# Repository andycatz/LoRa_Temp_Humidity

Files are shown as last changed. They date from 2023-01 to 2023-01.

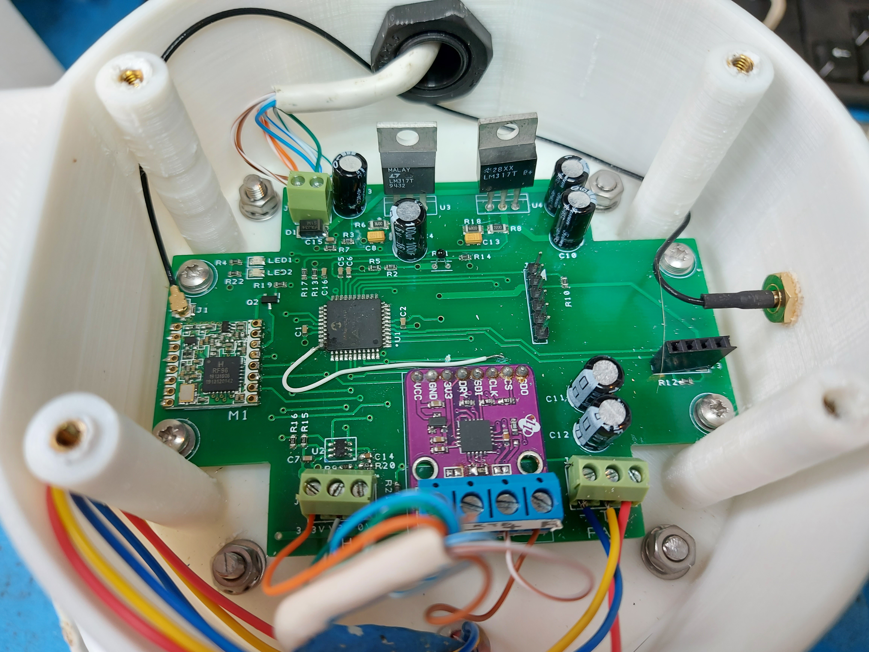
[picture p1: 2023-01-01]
Photos/20210724_112519.jpg

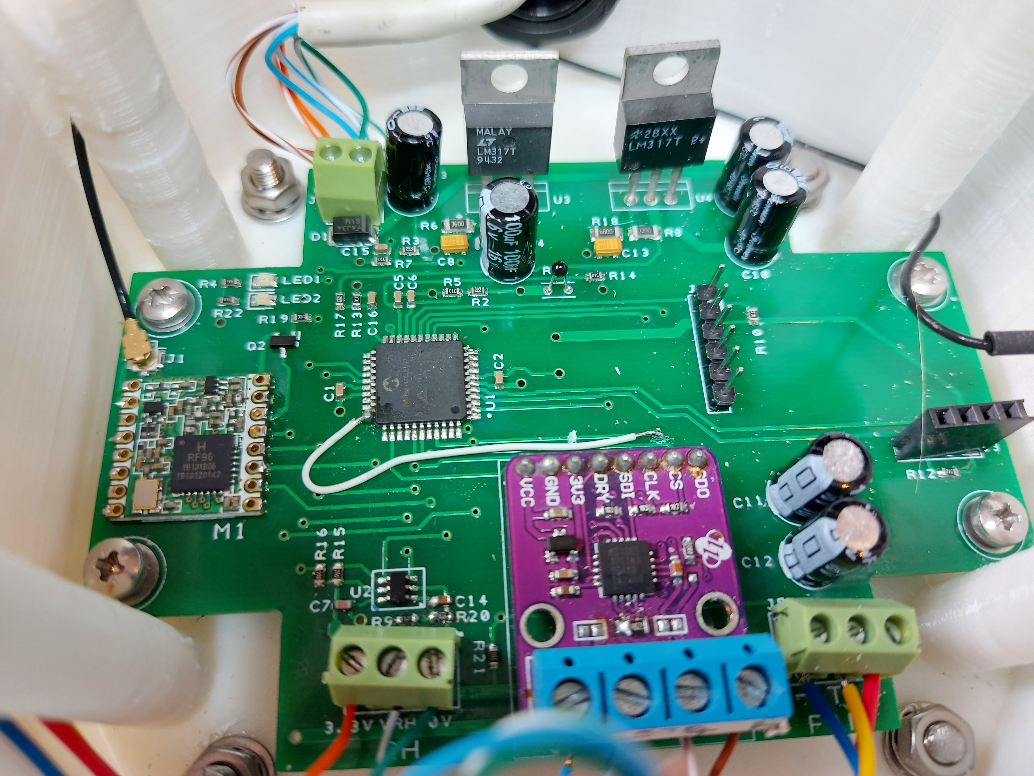
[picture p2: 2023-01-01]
Photos/20210724_112526.jpg

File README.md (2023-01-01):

# LoRa_Temp_Humidity
Outdoor temperature and humidity sensor with LoRa transmitter
The microcontroller wakes up once per minute and takes a temperature and relative humidity reading.
It then transmits that data as a 50 byte packet using the LoRa transmitter module (RFM95W).
The data is received by the LoRa receiver on the Raspberry pi.
All calibration is done at the receiver end.
This does NOT use LoRaWAN.
Schematic and PCB are designed using Design Spark.
Enclosure was designed using Fusion 360.
Software was written in C using MPLab X with XC8 compiler.

This sensor requires DC 9V power to run the electronics and the fan.  A battery is possible but
it would need to be reasonable large e.g. lead-acid 12V.
The fan is used to pass ambient air over the sensors and to prevent the outer walls of the enclosure
from heating up the sensor.
The 12V fan is run at approximately 5V so that it should have a long life time.  An IP65 or thereabouts
rated fan should be used, otherwise the fan bearings will rust within a few months.
In addition to the outside temperature and relative humidity, the sensor also reports back its own
internal temperature as well as the supply voltage, microcontroller supply voltage and fan voltage.

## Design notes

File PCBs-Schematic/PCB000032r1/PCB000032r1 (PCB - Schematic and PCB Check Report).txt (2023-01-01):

Schematic and PCB Check Report
------------------------------

Report Written:     Saturday, September 07, 2019
Project Path:       D:\Documents\Design Spark\000000's\PCB000032r1\PCB000032r1.prj
Design Path:        D:\Documents\Design Spark\000000's\PCB000032r1\PCB000032r1.pcb
Design Title:       
Created:            07/09/2019 17:56:36
Last Saved:         07/09/2019 18:29:10
Editing Time:       32 min
Units:              mm (precision 2)

Checking integrity of Schematic and Pcb designs in project "PCB000032r1"
========================================================================

End Of Report.

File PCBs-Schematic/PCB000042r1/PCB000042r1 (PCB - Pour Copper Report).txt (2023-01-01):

Pour Copper Report
------------------

Report Written:     Friday, June 25, 2021
Project Path:       D:\Documents\Design Spark\000000's\PCB000042r1\PCB000042r1.prj
Design Path:        D:\Documents\Design Spark\000000's\PCB000042r1\PCB000042r1.pcb
Design Title:       
Created:            25/05/2021 19:34:24
Last Saved:         25/06/2021 18:57:42
Editing Time:       444 min
Units:              mm (precision 2)

End Of Report.

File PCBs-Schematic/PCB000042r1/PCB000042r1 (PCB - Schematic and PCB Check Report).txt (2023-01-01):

Schematic and PCB Check Report
------------------------------

Report Written:     Thursday, June 24, 2021
Project Path:       D:\Documents\Design Spark\000000's\PCB000042r1\PCB000042r1.prj
Design Path:        D:\Documents\Design Spark\000000's\PCB000042r1\PCB000042r1.pcb
Design Title:       
Created:            25/05/2021 19:34:24
Last Saved:         24/06/2021 20:44:52
Editing Time:       335 min
Units:              mm (precision 2)

Checking integrity of Schematic and Pcb designs in project "PCB000042r1"
========================================================================

End Of Report.

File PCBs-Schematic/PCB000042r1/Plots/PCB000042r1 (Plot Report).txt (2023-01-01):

Plot Report
-----------

Report Written:     Friday, June 25, 2021
Project Path:       D:\Documents\Design Spark\000000's\PCB000042r1\PCB000042r1.prj
Design Path:        D:\Documents\Design Spark\000000's\PCB000042r1\PCB000042r1.pcb
Design Title:       
Created:            25/05/2021 19:34:24
Last Saved:         25/06/2021 20:06:50
Editing Time:       514 min
Units:              mm (precision 2)

Device Settings
===============

Gerber Settings
===============

    Leading zero suppression.
    G01 assumed throughout.
    Line termination <*> <CR> <LF>.
    3.5 format absolute inches.

    Format commands defined in Gerber file.
    Aperture table defined in Gerber file.
    Hardware arcs allowed.

Drill Settings
==============

    Excellon Format 2
    Format 3.5 absolute in mm.
    Zero suppression Leading

Plots Output
============

Gerber Output
=============

D:\Documents\Design Spark\000000's\PCB000042r1\Plots\PCB000042r1 - Top Silkscreen.gbr

    Layers:
    ------------------
    Top Silkscreen

    D-Code Shape  (thou)
    -----------------------
    D10    Round 5.00
    D11    Round 7.87
    D12    Round 8.00
    D13    Round 3.94
    D14    Round 10.00
    D17    Round 25.00

Gerber Output
=============

D:\Documents\Design Spark\000000's\PCB000042r1\Plots\PCB000042r1 - Top Copper.gbr

    Layers:
    --------------
    Top Copper

    D-Code Shape  (thou)
    --------------------------------------------------------------
    D16    Round 50.00
    D17    Round 25.00
    D19    Round 15.00
    D70    Round 48.00
    D71    Rectangle 22.00 X 59.00  Rotation 90
    D20    Rectangle 22.00 X 59.00
    D22    Square 80.00
    D23    Round 80.00
    D24    Rectangle 35.43 X 55.12
    D26    Rectangle 33.46 X 39.37
    D27    Rectangle 33.46 X 39.37  Rotation 90
    D28    Rectangle 30.71 X 38.58  Rotation 90
    D29    Rectangle 23.62 X 41.34
    D72    Rectangle 30.71 X 38.58
    D73    Round 43.31
    D75    Rectangle 41.34 X 86.61
    D76    Rectangle 39.37 X 41.34
    D77    Round 251.97
    D103   Rounded Rectangle 59.06 X 98.43 X 19.69  Rotation 90
    D104   Round 60.00
    D123   Round 56.00
    D124   Rectangle 21.65 X 47.24  Rotation 90
    D125   Square 59.06
    D126   Round 70.00
    D127   Rectangle 68.90 X 104.33
    D128   Square 60.00
    D129   Rectangle 41.34 X 70.87
    D130   Rectangle 43.31 X 70.87
    D131   Rectangle 24.41 X 57.87
    D132   Rectangle 59.00 X 59.00  Rotation 90
    D133   Round 59.00

Gerber Output
=============

D:\Documents\Design Spark\000000's\PCB000042r1\Plots\PCB000042r1 - Top Solder Mask.gbr

    Layers:
    -------------------
    Top Solder Mask

    D-Code Shape  (thou)
    --------------------------------------------------------------
    D81    Rectangle 28.00 X 65.00  Rotation 90
    D82    Rectangle 28.00 X 65.00
    D84    Square 86.00
    D85    Round 86.00
    D86    Rectangle 41.43 X 61.12
    D88    Rectangle 39.46 X 45.37
    D89    Rectangle 39.46 X 45.37  Rotation 90
    D90    Rectangle 36.71 X 44.58  Rotation 90
    D91    Rectangle 29.62 X 47.34
    D92    Rectangle 36.71 X 44.58
    D93    Round 49.31
    D95    Rectangle 47.34 X 92.61
    D96    Rectangle 45.37 X 47.34
    D97    Round 257.97
    D121   Rounded Rectangle 59.06 X 98.43 X 19.69  Rotation 90
    D134   Rectangle 27.65 X 53.24  Rotation 90
    D135   Square 65.06
    D136   Round 66.00
    D137   Round 76.00
    D138   Rectangle 74.90 X 110.33
    D139   Square 66.00
    D140   Rectangle 47.34 X 76.87
    D141   Rectangle 49.31 X 76.87
    D142   Rectangle 30.41 X 63.87
    D143   Rectangle 65.00 X 65.00  Rotation 90
    D144   Round 65.00

Gerber Output
=============

D:\Documents\Design Spark\000000's\PCB000042r1\Plots\PCB000042r1 - Bottom Copper.gbr

    Layers:
    -----------------
    Bottom Copper

    D-Code Shape  (thou)
    --------------------------------------------------------------
    D10    Round 5.00
    D14    Round 10.00
    D16    Round 50.00
    D19    Round 15.00
    D70    Round 48.00
    D22    Square 80.00
    D23    Round 80.00
    D73    Round 43.31
    D77    Round 251.97
    D103   Rounded Rectangle 59.06 X 98.43 X 19.69  Rotation 90
    D104   Round 60.00
    D123   Round 56.00
    D125   Square 59.06
    D126   Round 70.00
    D128   Square 60.00
    D132   Rectangle 59.00 X 59.00  Rotation 90
    D133   Round 59.00

Gerber Output
=============

D:\Documents\Design Spark\000000's\PCB000042r1\Plots\PCB000042r1 - Bottom Solder Mask.gbr

    Layers:
    ----------------------
    Bottom Solder Mask

    D-Code Shape  (thou)
    --------------------------------------------------------------
    D84    Square 86.00
    D85    Round 86.00
    D93    Round 49.31
    D97    Round 257.97
    D121   Rounded Rectangle 59.06 X 98.43 X 19.69  Rotation 90
    D135   Square 65.06
    D136   Round 66.00
    D137   Round 76.00
    D139   Square 66.00
    D143   Rectangle 65.00 X 65.00  Rotation 90
    D144   Round 65.00

Gerber Output
=============

D:\Documents\Design Spark\000000's\PCB000042r1\Plots\PCB000042r1 - Gerber Drill Data - [Through Hole].gbr

    Layers:
    ------------------
    [Through Hole]

    D-Code Shape  (thou)
    -----------------------
    D145   Round 32.00
    D146   Round 24.00
    D147   Round 39.37
    D148   Round 23.62
    D149   Round 35.00
    D150   Round 42.00
    D151   Round 31.50
    D152   Round 125.98
    D153   Round 39.00

NC Drill Output
===============

D:\Documents\Design Spark\000000's\PCB000042r1\Plots\PCB000042r1 - NC Drill Data - [Through Hole].drl

    Output:
    ---------------------------
    Plated Round Drill Holes
    Plated Slots

    Tool  Size           Count   ID
    --------------------------------------
    T001  0.02362 inches 2     E
    T002  0.02400 inches 35    B
    T003  0.03150 inches 12    J
    T004  0.03200 inches 15    L
    T005  0.03500 inches 5     I
    T006  0.03900 inches 8     N
    T007  0.03937 inches 29    D
    T008  0.04200 inches 6     M
    T009  0.12598 inches 4     F
    --------------------------------------
    Total                116
    --------------------------------------

D:\Documents\Design Spark\000000's\PCB000042r1\Plots\PCB000042r1 - NC Drill Data - [Through Hole] (Unplated).drl

    Output:
    -----------------------------
    Unplated Round Drill Holes
    Unplated Slots

    Tool  Size Count   ID
    ----------------------------
    ----------------------------
    Total      0
    ----------------------------

Gerber Output
=============

D:\Documents\Design Spark\000000's\PCB000042r1\Plots\PCB000042r1 - Drill Ident Drawing - [Through Hole].gbr

    Layers:
    ------------------
    [Through Hole]

Drill Ident Drawing
===================

    Drill Plated Size Shape ID
    -----------------------------------
    24    Y      100  Round B
    39    Y      100  Round D
    24    Y      100  Round E
    126   Y      100  Round F
    35    Y      100  Round I
    31    Y      100  Round J
    32    Y      100  Round L
    42    Y      100  Round M
    39    Y      100  Round N

    D-Code Shape  (thou)
    -----------------------
    D10    Round 5.00
    D99    Round 100.00

Gerber Output
=============

D:\Documents\Design Spark\000000's\PCB000042r1\Plots\PCB000042r1 - Outline.gbr

    Layers:
    ------------------
    Board Outlines

    D-Code Shape  (thou)
    -----------------------
    D10    Round 5.00

End Of Report.

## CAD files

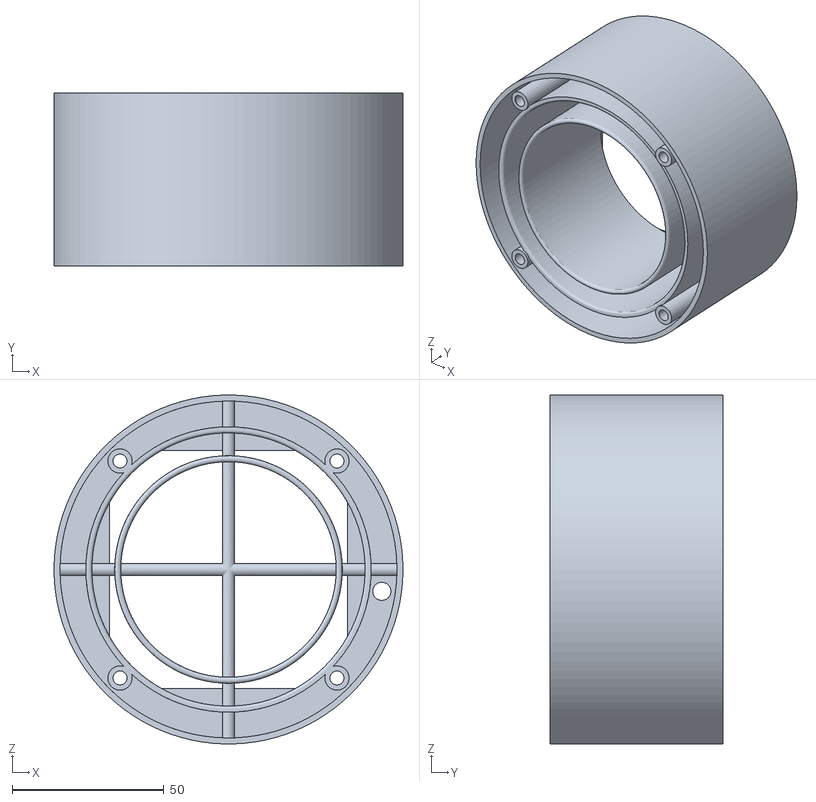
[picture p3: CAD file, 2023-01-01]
3D Models/Fan Aspirated Enclosure MK2/Main Body.stl
115.0 x 57.0 x 114.9

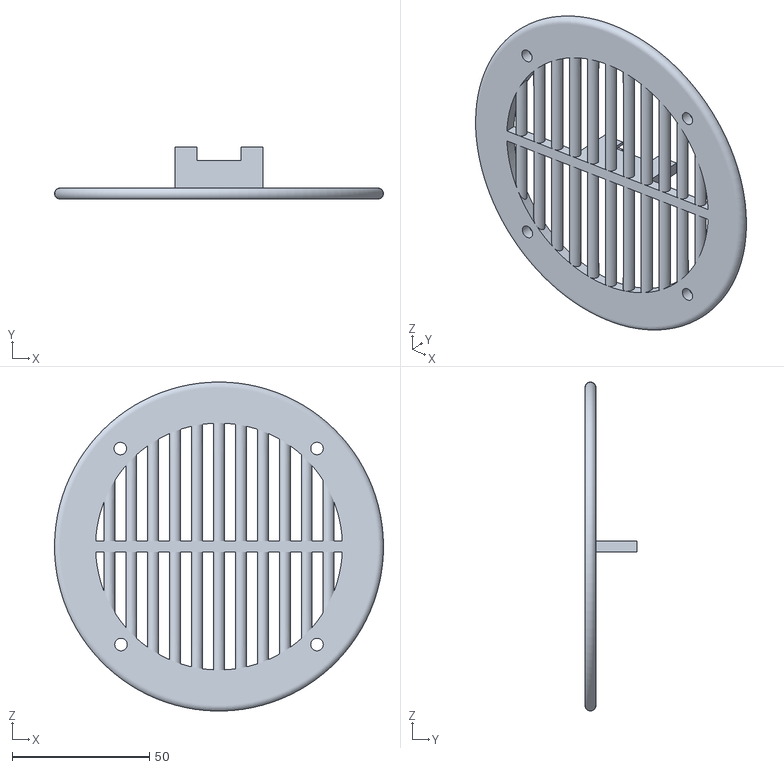
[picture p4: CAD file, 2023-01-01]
3D Models/Fan Aspirated Enclosure MK2/Inlet Cover.stl
120.0 x 19.0 x 120.0

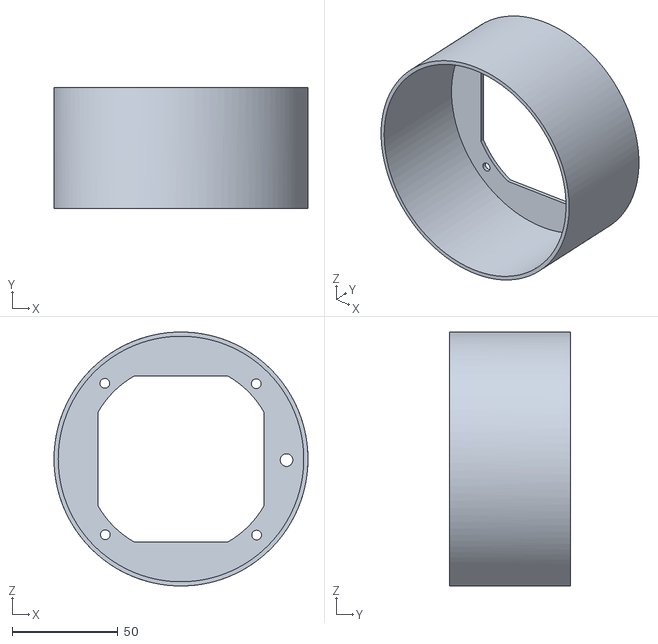
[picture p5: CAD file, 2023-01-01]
3D Models/Fan Aspirated Enclosure MK2/Fan Holder.stl
120.0 x 57.0 x 120.0

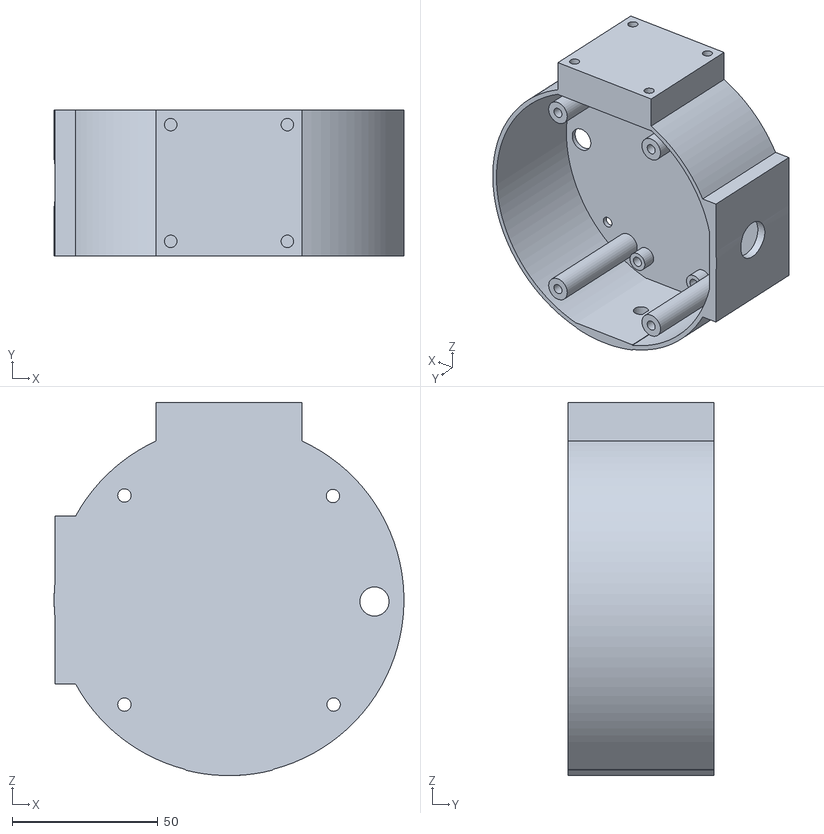
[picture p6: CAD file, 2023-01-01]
3D Models/Fan Aspirated Enclosure MK2/Electronics Box.stl
119.9 x 50.0 x 127.9

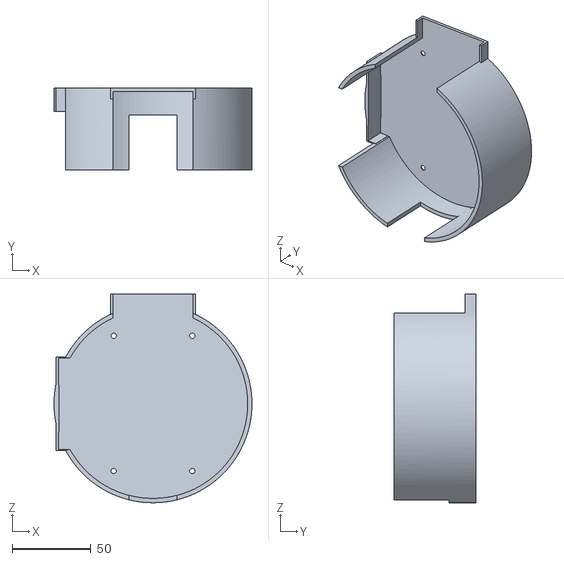
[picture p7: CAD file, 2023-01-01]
3D Models/Fan Aspirated Enclosure MK2/Electronics Cover.stl
126.0 x 52.0 x 132.7

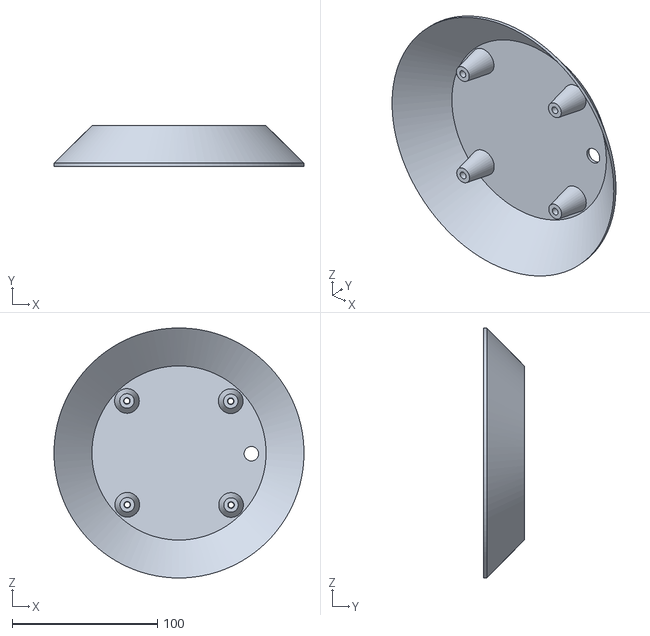
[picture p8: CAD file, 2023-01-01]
3D Models/Fan Aspirated Enclosure MK2/Top Cover.stl
172.2 x 28.1 x 172.2

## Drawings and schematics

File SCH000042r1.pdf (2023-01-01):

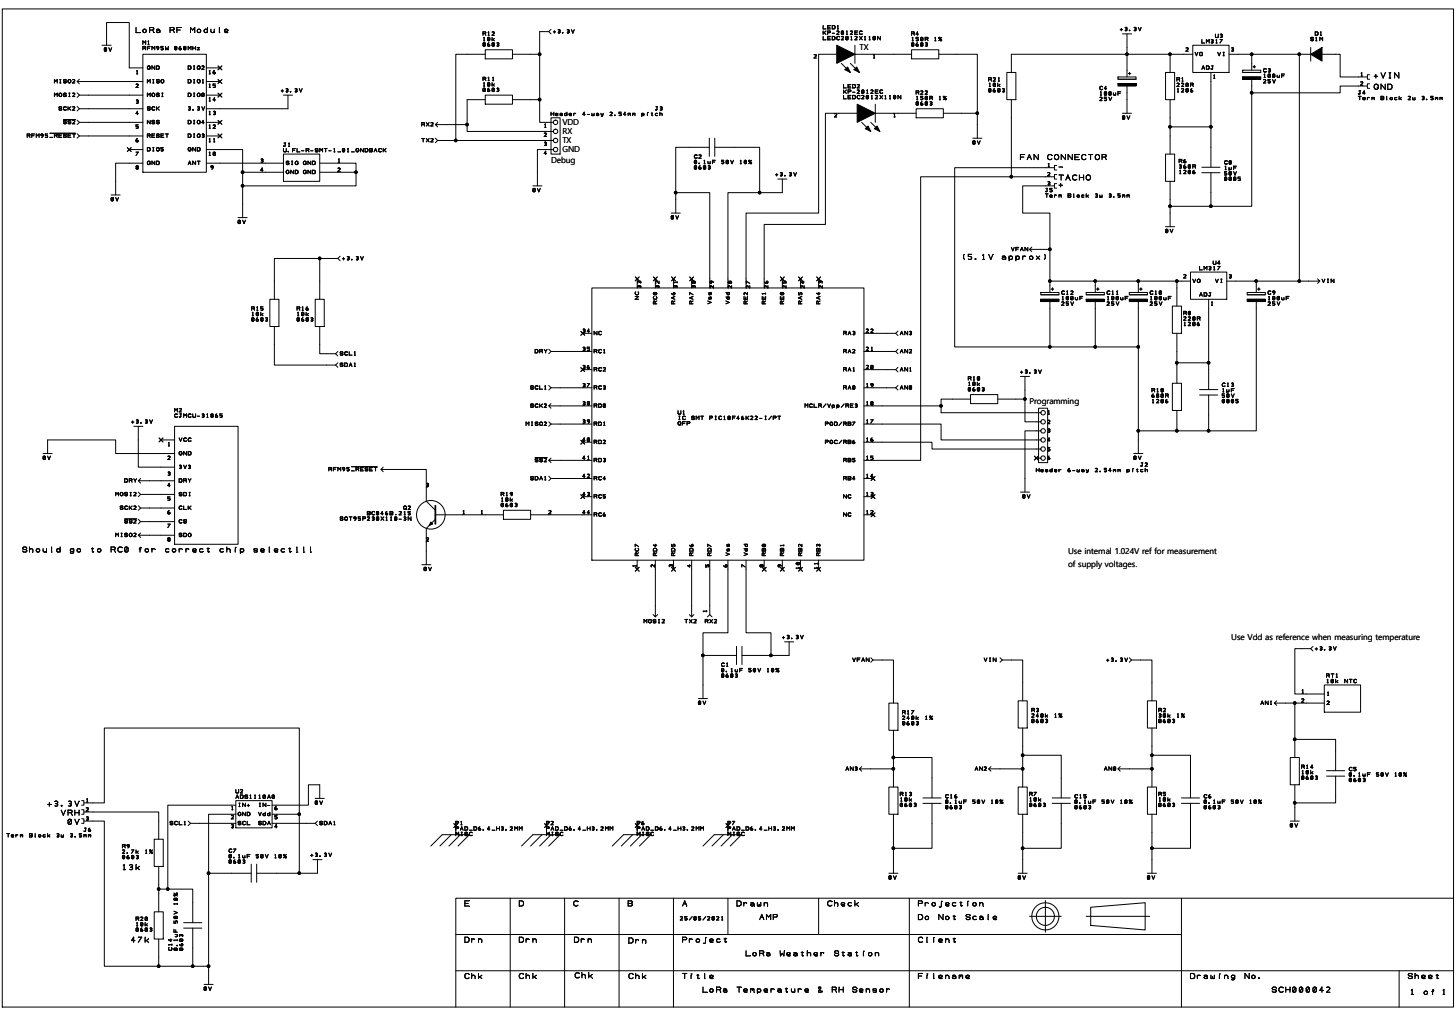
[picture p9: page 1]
Programming; Debug; VDD; GND

Use internal 1.024V ref for measurement
of supply voltages.

Use Vdd as reference when measuring temperature

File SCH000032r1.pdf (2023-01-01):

A | B | C | D | E | F

1

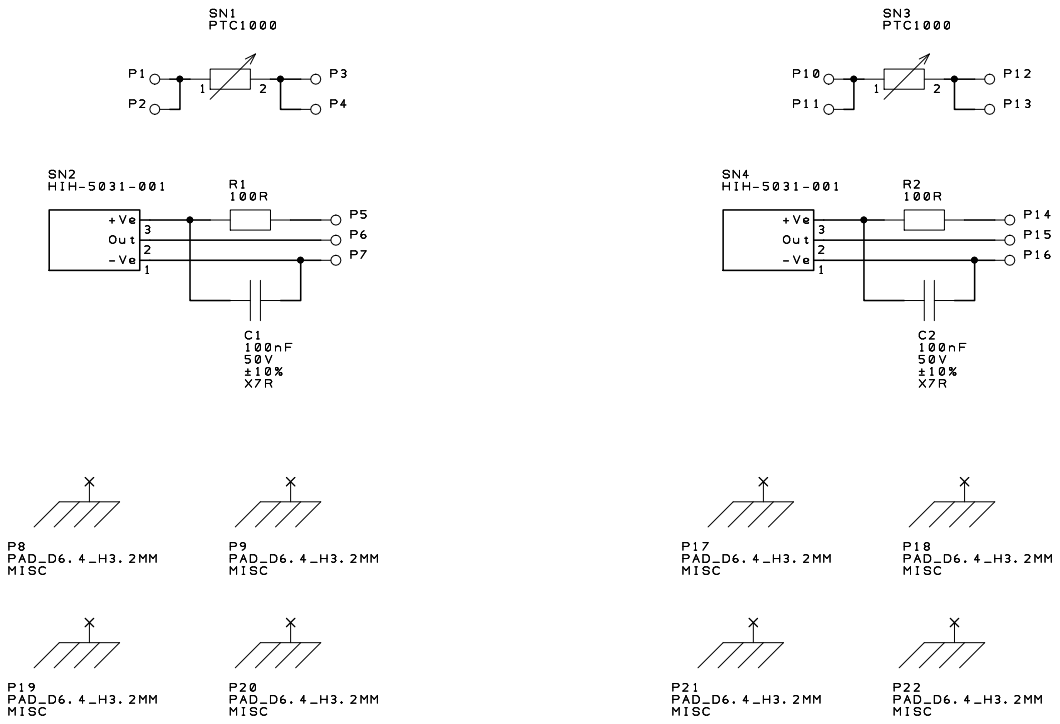
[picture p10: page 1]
SHEET:; PROJECT:; REVISION:; DATE:; STATUS:; DRAWING TITLE: DRAWN BY:

DESIGNSPARK PCB available for FREE at www.DesignSpark.com/PCB

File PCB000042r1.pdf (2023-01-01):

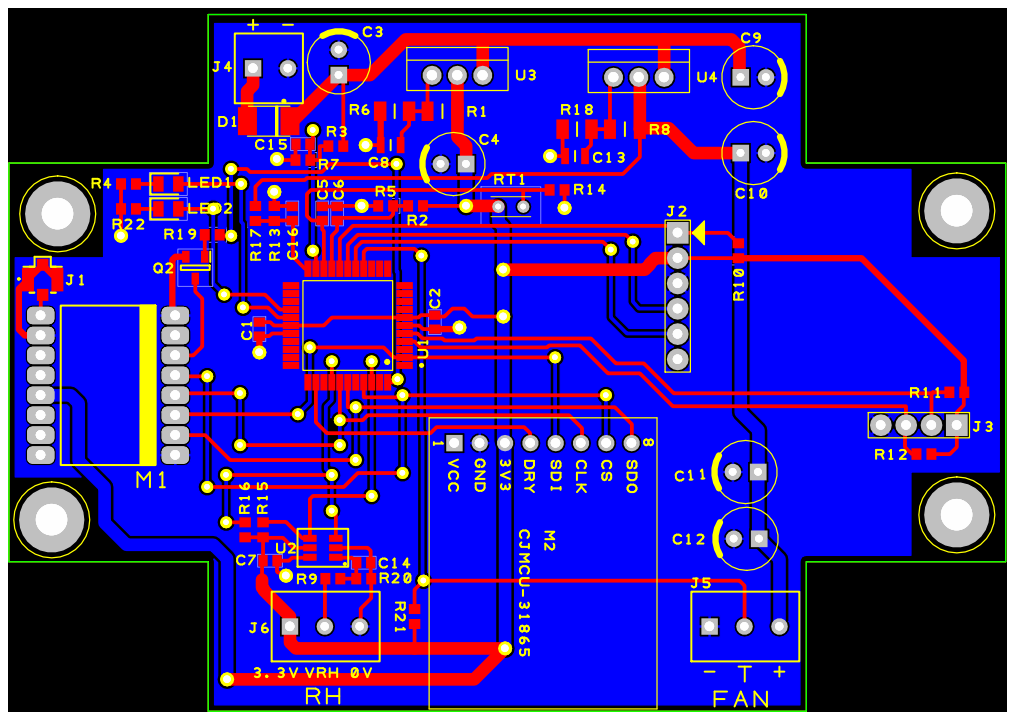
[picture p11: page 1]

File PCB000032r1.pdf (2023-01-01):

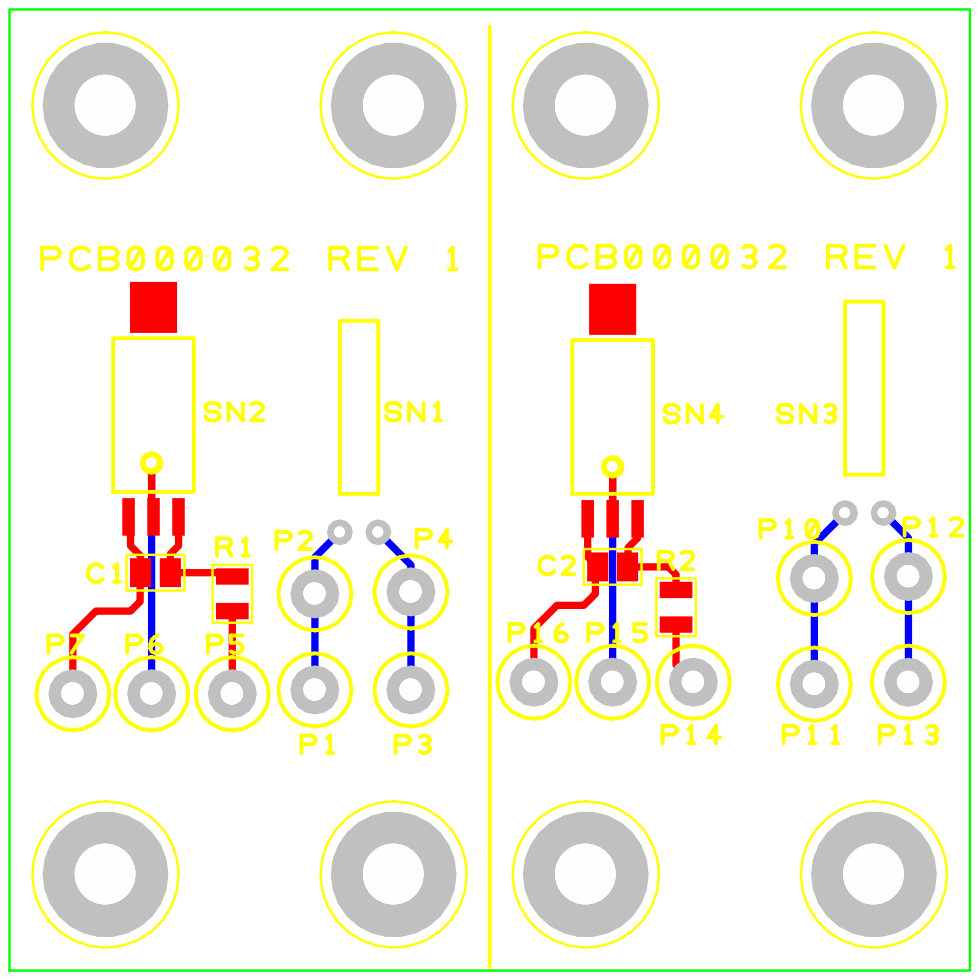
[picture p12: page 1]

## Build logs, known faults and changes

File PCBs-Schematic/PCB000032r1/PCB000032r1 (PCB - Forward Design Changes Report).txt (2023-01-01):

Forward Design Changes Report
-----------------------------

Report Written:     Saturday, September 07, 2019
Project Path:       D:\Documents\Design Spark\000000's\PCB000032r1\PCB000032r1.prj
Design Path:        D:\Documents\Design Spark\000000's\PCB000032r1\PCB000032r1.pcb
Design Title:       
Created:            07/09/2019 17:56:36
Last Saved:         07/09/2019 18:29:10
Editing Time:       32 min
Units:              mm (precision 2)

Added component reference "P19" of component "PAD_D6.4_H3.2MM", package "MISC".
Added component reference "P20" of component "PAD_D6.4_H3.2MM", package "MISC".
Added component reference "P21" of component "PAD_D6.4_H3.2MM", package "MISC".
Added component reference "P22" of component "PAD_D6.4_H3.2MM", package "MISC".

End Of Report.

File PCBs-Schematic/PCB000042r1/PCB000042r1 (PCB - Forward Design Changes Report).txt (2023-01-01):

Forward Design Changes Report
-----------------------------

Report Written:     Thursday, June 24, 2021
Project Path:       D:\Documents\Design Spark\000000's\PCB000042r1\PCB000042r1.prj
Design Path:        D:\Documents\Design Spark\000000's\PCB000042r1\PCB000042r1.pcb
Design Title:       
Created:            25/05/2021 19:34:24
Last Saved:         24/06/2021 20:44:52
Editing Time:       335 min
Units:              mm (precision 2)

Added net "N0106".
Added net "N0107".

Added component reference "LED2" of component "KP-2012EC", package "LEDC2012X110N".
Added component reference "R22" of component "CRCW0603150RFKTA", package "RESC1608X50N".
Added value "Value=150R 1%" to component reference "R22".
Added value "Package=0603" to component reference "R22".

Connected pin "U1.26" to net "N0106".
Connected pin "LED2.1" to net "N0107".
Connected pin "LED2.2" to net "N0106".
Connected pin "R22.1" to net "N0107".
Connected pin "R22.2" to net "0V".

End Of Report.

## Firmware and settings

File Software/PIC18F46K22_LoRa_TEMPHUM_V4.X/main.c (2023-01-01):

/*
 * File:   main.c
 * Author: andym
 *
 * Created on 16 May 2021, 20:51
 * 
 * Version 3, 17th July 2021:  Added supply voltages and fan speed sensing.
 * Version 4, 18th Sept 2021:  Changed to use fixed 50 byte universal packet size.
 * 
 * LoRa Temperature and Relative Humidity Sensor Transmitter.
 * 
 * Temperature sensed using MAX31865 PT1000 interface connected to SPI.
 * RH sensed using HIH5031 connected to ADS1110 on I2C interface.
 * 
 * RA2 controls sensor & RS232 supply & divider & reference (turn off when not in use - high is off, low is on)
 * driven by PNP transistor from port pin to get enough voltage drive.
 * 
 * RFM95W LoRa Module

 * AN0 reads battery voltage through a resistor divider
 * AN1 reads local temperature through 10k NTC and 10k resistor as a divider from 3.3V
 * AN2 reads VIN
 * AN3 reads Fan Voltage
 * RE2 has red LED
 * RE1 has green LED
 * RB5 has fan tacho input.
 * 
 * Internal oscillator used at 64MHz (16MHz with 4x PLL)
 * 
 * Reference Sensor Types
 * 0    BASE RECEIVER
 * 1    Rain
 * 2    UV/Visible Light
 * 3    Temp/RH* (This sensor)
 * 4    Extra temp(s)
 * 5    Soil moisture
 * 6    Lightning
 * 7    Radiation
 * 8    Wind
 * 9    Leaf wetness
 * 10   Electric Field
 */


#include <xc.h>
#include <stdio.h>
#include <stdint.h>
#include <stdlib.h>
#include "config.h"
#include "defines.h"
#include "usart2.h"
#include "LoRa.h"
#include "i2c1.h"
#include "MAX31865.h"
#include "ADS1110.h"
#include "CRC16.h"

#define DEBUG 1
#define TX_FREQ 866.5
#define SYNC_WORD 0x55
#define BATT_UVLO 2100 //2V UVLO below which transmitter operation is prevented
#define BATT_UVLO_ATOD BATT_UVLO/4
#define DATA_PACKET_LENGTH 50
#define ID0 0x00
#define ID1 0x03
#define SOFTWARE_VERSION 0x04

void configureIO();
uint16_t readBattery();
uint16_t readTemperature();
uint16_t readVSupply();
uint16_t readVFan();
void setupAtoD();
uint16_t readRH();
void transmitData(void);
void disablePeripherals(void);
void setupInterruptPin(void); //Sets up interrupt on fan tacho input

uint8_t txData[DATA_PACKET_LENGTH]; //Transmit buffer
uint8_t address[8] = {0x6C,0x27,0xDA,0x88,0x2F,0xE4,0x1A,0xF0}; //This should be unique
uint16_t batt=0; //Battery (microcontroller supply) voltage reading from internal A to D
uint16_t temp=0; //Temperature reading from internal A to D
uint16_t vsupply=0; //Supply voltage reading from internal A to D
uint16_t vfan=0;  //Fan voltage reading from internal A to D
uint32_t messageCount=0;
uint16_t extTemp=0; //Temperature reading from MAX31865
uint16_t rh=0;      //RH reading from ADS1110
uint32_t fanTachoCount=0; //Counts fan tacho pulses, resets everytime a transmit occurs.

void main(void) {
    setupInterruptPin();
    while(1){
        configureIO();
        ClrWdt(); //Reset watchdog timer
        GREEN_LED=1;
        configureSPI();
        __delay_ms(10); //Wait for things to power up
        MAX31865writeConfigByte(0xC1); //Configure the device
        __delay_ms(100); //Wait for temperature reading to stabilise
        batt = readBattery();
        temp = readTemperature();
        vsupply = readVSupply();
        vfan = readVFan();
        extTemp = MAX31865readData();
        rh = readRH();
        

        if(batt>BATT_UVLO_ATOD){
            INTCONbits.GIE=0; //Global interrupt disable
            transmitData();
            INTCONbits.GIE=1; //Global interrupt enable
        }
        else{
            //Flash the red LED 3 times
            RED_LED=1; //Red LED on
            __delay_ms(300);
            RED_LED=0;
            __delay_ms(300);
            RED_LED=1; //Red LED on
            __delay_ms(300);
            RED_LED=0;
            __delay_ms(300);
            RED_LED=1; //Red LED on
            __delay_ms(300);
            RED_LED=0;
            __delay_ms(300);
        }
        



        if(DEBUG){
            printf("BATT %d\r\n", batt);
            printf("TEMP %d\r\n", temp);
            printf("EXT TEMP %d\r\n", extTemp);
            printf("EXT RH %d\r\n", rh);
            printf("VSUPP %d\r\n", vsupply);
            printf("VFAN %d\r\n", vfan);
            printf("TACHO %d\r\n", fanTachoCount);
        }
        //disablePeripherals(); //Turn everything off
        //No sleeping, unit has permanent power
        GREEN_LED=0; //Off when waiting
        fanTachoCount=0;
        for(uint16_t i=0;i<60;i++){
            __delay_ms(1000);
            ClrWdt(); //Reset watchdog timer
        }

    }
}

void transmitData(){
    if(DEBUG){
        printf("Transmitting...\r\n");
    }

    
    
    txData[0] = DATA_PACKET_LENGTH;
    txData[1] = ID0; //Copy in the ID
    txData[2] = ID1; //Copy in the ID
    for(uint8_t i=0;i<8;i++){
        txData[i+3] = address[i]; //Copy in the address
    }
    txData[11] = SOFTWARE_VERSION;
    
    //Message count
    txData[12]=(uint8_t)((messageCount>>24)&0xFF); //MSB
    txData[13]=(uint8_t)((messageCount>>16)&0xFF); //Upper middle
    txData[14]=(uint8_t)((messageCount>>8)&0xFF); //Lower middle
    txData[15]=(uint8_t)((messageCount & 0xFF)); //LSB
    
    //MCU supply voltage value (10-bit in 2 bytes)
    txData[16]=(uint8_t)((batt>>8)&0xFF); //MSB
    txData[17]=(uint8_t)(batt & 0xFF); //LSB
    
    //Sensor local temperature value (16-bit)
    txData[18]=(uint8_t)((temp>>8)&0xFF); //MSB
    txData[19]=(uint8_t)(temp & 0xFF); //LSB
    
    txData[20] = (uint8_t)((vsupply>>8)&0xFF); //MSB
    txData[21] = (uint8_t)((vsupply & 0xFF)); //LSB
    
    txData[22] = (uint8_t)((vfan>>8)&0xFF); //MSB
    txData[23] = (uint8_t)((vfan & 0xFF)); //LSB
    
    //External temperature
    txData[24]=(uint8_t)((extTemp>>8)&0xFF); //MSB
    txData[25]=(uint8_t)((extTemp)&0xFF); //LSB
    
    //External relative humidity
    txData[26]=(uint8_t)((rh>>8)&0xFF); //MSB
    txData[27]=(uint8_t)((rh & 0xFF)); //LSB
    
    //Fan tacho count
    txData[28] = (uint8_t)((fanTachoCount>>24)&0xFF); //MSB
    txData[29] = (uint8_t)((fanTachoCount>>16)&0xFF); //Byte 2
    txData[30] = (uint8_t)((fanTachoCount>>8)&0xFF); //Byte 3
    txData[31] = (uint8_t)((fanTachoCount & 0xFF)); //LSB
    
    //Fill the rest of the data area with 0
    for(uint8_t i=32;i<48;i++){
        txData[i] = 0;
    }
    
    //Calculate CRC16 and add to end of message
    unsigned short int calcCRC = CRC16(txData, DATA_PACKET_LENGTH-2);
    txData[49] = (calcCRC&0xFF00u)>>8u; //MSB
    txData[48] = (calcCRC&0xFF); //LSB
    
    //Set the transmitter up and send the data
    LoRaStart(TX_FREQ, SYNC_WORD); //Configure module
    if(DEBUG){
        printf("TXF: %f\r\n", LoRaGetFrequency());
    }
    LoRaClearIRQFlags();
    RED_LED=1; //Red LED on
    LoRaTXData(txData, DATA_PACKET_LENGTH); //Send data
    if(DEBUG){
        printf("Wait for end of transmission...\r\n");
    }
    uint8_t j=0;
    for(j=0;j<50;j++){
        uint8_t flags = LoRaGetIRQFlags();
        //printf("IRQ %d %d \r\n",j, flags);
        if(flags>0){
            break;
        }
        __delay_ms(10); //We are done with transmission
    }
    if(DEBUG){
        if(j>48){
            printf("TX Fail\r\n");
        }
        else{
            printf("Done.\r\n");
        }
    }
    LoRaSleepMode(); //Put module to sleep
    __delay_ms(10);
    messageCount++;
    RED_LED=0; //Red LED off
}

uint16_t readRH(){
    uint16_t rhTemp = readADS1110(ADS1110_ADDRESS);
    return rhTemp;
}

void configureIO(){
    //Internal oscillator
    OSCCONbits.IRCF=0b111; //Set internal clock to 16MHz
    OSCCONbits.OSTS=0; //Device is running from internal oscillator
    OSCCON2bits.PLLRDY=1; //System clock comes from 4xPLL
    OSCTUNEbits.PLLEN=1;//Enable PLL
    
    //SPI2 pins
    TRISDbits.RD1=1; //SDI2 set as input (MISO2)
    TRISDbits.RD4=0; //SDO2 set as output (MOSI2)
    TRISDbits.RD0=0; //SCK2 set as output (SCK2)
    TRISDbits.RD3=0; //#SS2 set as output (CS2)
    TRISCbits.RC0=0; //#SS for MAX31865
    ANSELDbits.ANSD0=0; //Turn off analogue function of port pin
    ANSELDbits.ANSD1=0;
    ANSELDbits.ANSD2=0;
    ANSELDbits.ANSD4=0;
    
    PMD2bits.ADCMD=0; //Turn ADC on
    if(DEBUG){
        PMD0bits.UART2MD=0; //Turn UART2 on
    }
    PMD1bits.MSSP1MD=0; //Turn I2C on
    PMD1bits.MSSP2MD=0; //Turn SPI2 on
    ANSELAbits.ANSA2=0; //Analogue off
    TRISAbits.RA2=0; //Output
    LATAbits.LATA2=0; //External circuitry on
    ANSELEbits.ANSE1=0; //Turn off analogue on RE1
    ANSELEbits.ANSE2=0; //Turn off analogue on RE2
    ANSELBbits.ANSB4=0; //Turn off analogue on RB4
    TRISEbits.RE1=0; //Green LED for status
    TRISEbits.RE2=0; //Red LED for status
    TRISBbits.RB5=1; //Input (fan tacho)
    ANSELBbits.ANSB5=0; //Turn off analogue on RB5
    RED_LED=0; //Red LED off
    if(DEBUG){
        USART2_Start(BAUD_57600); //Start USART2
    }
    setupAtoD(); //Setup to read AN0 (reads supply voltage [battery])
    I2C1_Initialize(100000); //Starts I2C module 1 (100kHz fixed)
    I2C1_Check_Data_Stuck(); //Check if bus is stuck and attempt to unstick it.
    configADS1110(); //Configure the external A to D converter.
}

void setupAtoD(){
    //Setup AN0 for a to d converter (RA0)
    
    //Set ANSELbit to disable digital input buffer
    ANSELAbits.ANSA0=1;
    ANSELAbits.ANSA1=1;
    ANSELAbits.ANSA2 = 1;
    ANSELAbits.ANSA3 = 1;
    
    //Set TRISXbit to disable digital output driver
    TRISAbits.RA0=1;
    TRISAbits.RA1=1;
    TRISAbits.RA2 = 1;
    TRISAbits.RA3 = 1;
    
    //Set voltage references
    ADCON1bits.PVCFG=0; //A/D Vref+ connected to Vdd
    ADCON1bits.NVCFG=0; //A/D Vref- connected to internal signal AVss
    VREFCON0bits.FVRS=0b01; //Fixed voltage reference is 1.024V
    VREFCON0bits.FVREN=1; //Enable internal reference
    
    //Select channel 0 for A to D
    ADCON0bits.CHS=0;
    
    //Set A to D acquisition time
    ADCON2bits.ACQT=0b010; //Tacq = 4 Tad (4µs)
    
    //Set A to D clock period
    ADCON2bits.ADCS=0b110; //Clock period set to Fosc/64 = 1µs (64MHz clock)
    
    //Set result format
    ADCON2bits.ADFM = 1; //Data is mostly in the ADRESL register with 2 bits in the ADRESH register
    
    //Turn on the A to D module
    ADCON0bits.ADON=1;
}

/**
 * Reads the microcontroller supply voltage A to D
 */
uint16_t readBattery(){
    //Select channel 0 for A to D
    ADCON0bits.CHS=0;
    ADCON1bits.PVCFG=0b10; //A/D Vref+ connected to internal reference FVR BUF2
    ADCON0bits.GO_NOT_DONE=1; //Start the A to D process
    while(ADCON0bits.GO_NOT_DONE){
        //Wait for conversion to complete (about 15µs)
    }
    uint16_t result = ADRESH * 256 + ADRESL; //Read A to D result
    return result;
}

uint16_t readTemperature(){
    ADCON1bits.PVCFG=0; //A/D Vref+ connected to Vdd
    //Select channel 1 for A to D
    ADCON0bits.CHS=1;
    ADCON0bits.GO_NOT_DONE=1; //Start the A to D process
    while(ADCON0bits.GO_NOT_DONE){
        //Wait for conversion to complete (about 15µs)
    }
    uint16_t result = ADRESH * 256 + ADRESL; //Read A to D result
    return result;
}

/**
 * Reads the incoming supply voltage A to D
 */
uint16_t readVSupply(){
    //Select channel 2 for A to D
    ADCON0bits.CHS=0b10;
    ADCON1bits.PVCFG=0b10; //A/D Vref+ connected to internal reference FVR BUF2
    ADCON0bits.GO_NOT_DONE=1; //Start the A to D process
    while(ADCON0bits.GO_NOT_DONE){
        //Wait for conversion to complete (about 15µs)
    }
    uint16_t result = ADRESH * 256 + ADRESL; //Read A to D result
    return result;
}

/**
 * Reads the fan voltage A to D
 */
uint16_t readVFan(){
    //Select channel 3 for A to D
    ADCON0bits.CHS=0b11;
    ADCON1bits.PVCFG=0b10; //A/D Vref+ connected to internal reference FVR BUF2
    ADCON0bits.GO_NOT_DONE=1; //Start the A to D process
    while(ADCON0bits.GO_NOT_DONE){
        //Wait for conversion to complete (about 15µs)
    }
    uint16_t result = ADRESH * 256 + ADRESL; //Read A to D result
    return result;
}

void disablePeripherals(){
    ADCON0bits.ADON=0; //Turn off A to D module
    //Set all pins as outputs
    TRISA=0;
    TRISB=0x01; //Set all outputs except RB0
    TRISC=0;
    TRISD=0;
    TRISE=0;
    LATA=0;
    LATB=0;
    LATC=0;
    LATD=0;
    LATE=0;
    LATAbits.LA2=1; //Turn off external peripherals
    //Deal with SDI in case LoRa module is driving it
    TRISDbits.RD1=1; //SDIx must have corresponding TRIS bit set (input)
    ANSELDbits.ANSD1=0; //Input buffer enabled
    LATDbits.LATD3=1; //Set SS high so LoRa chip is not selected
    //LATCbits.LATC0=1; //Set SS high for MAX31865 so it is not selected
    PMD0bits.UART2MD=1; //Turn off UART2
    PMD0bits.UART1MD=1; //Turn off UART1
    PMD0bits.TMR6MD=1; //Turn off timer 6
    PMD0bits.TMR5MD=1; //Turn off timer 5
    PMD0bits.TMR4MD=1; //Turn off timer 4
    PMD0bits.TMR3MD=1; //Turn off timer 3
    PMD0bits.TMR2MD=1; //Turn off timer 2
    PMD0bits.TMR1MD=1; //Turn off timer 1
    PMD0bits.SPI2MD=1; //Turn off SPI2
    PMD0bits.SPI1MD=1; //Turn off SPI1
    PMD1=0xFF; //Turn off all peripherals in PMD1 (including MSSP2 for SPI2)
    PMD2=0xFF; //Turn off all peripherals in PMD2 (ADC, comparators, CTMU)
}

void setupInterruptPin(void){
    INTCONbits.RBIE=1; //Enables the IOCx port change interrupt
    IOCBbits.IOCB5=1; //Enable interrupt on RB4 change
    INTCONbits.PEIE=1; //Enables unmasked peripheral interrupts
    INTCONbits.GIE=1; //Global interrupt enable
    INTCONbits.RBIF=0; //Clear interrupt flag for port B bits
}

void __interrupt() Isr(void){
    uint8_t bValue = PORTBbits.RB5; //Read port b
    if(bValue>0){
        //port bit has changed to a 1
        fanTachoCount++;
    }
    INTCONbits.RBIF=0; //Clear interrupt flag for port B
    //GREEN_LED=!GREEN_LED;
}

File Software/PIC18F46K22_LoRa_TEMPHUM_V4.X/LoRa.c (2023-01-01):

#include <xc.h>
#include "LoRa.h"
#include <stdint.h>
#include <stdio.h>

#define DEBUG 0

/**
 * Configures PIC and LoRa module RFM95W to start with specified frequency in MHz
 * from PIC18F46K22_LoRA_UVVIS_V2
 */
void LoRaStart(float freq, uint8_t syncWord){
    //Configure pin for LoRa module reset
    ANSELAbits.ANSA2=0; //Digital input buffer enabled
    
    
    //Configure SPI2 as master
    //Set up SPI pins first
    TRISDbits.RD1=1; //SDIx must have corresponding TRIS bit set (input)
    TRISDbits.RD4=0; //SDOx must have corresponding TRIS bit cleared (output)
    TRISDbits.RD0=0; //SCKx (Master mode) must have corresponding TRIS bit cleared (output)
    TRISDbits.RD3=0; //#SS must have corresponding TRIS bit cleared (output)
    ANSELDbits.ANSD1=0; //Input buffer enabled
    ANSELDbits.ANSD4=0; //Digital
    ANSELDbits.ANSD3=0; //Digital
    ANSELDbits.ANSD0=0; //Digital
    LATDbits.LATD3=1; //Set SS high so chip is not selected
    
    //Clock polarity
    SSP2CON1bits.CKP=0; //Clock idle low, active high
    SSP2STATbits.CKE=1; //Active to idle 1
    
    //Input data sampling
    SSP2STATbits.SMP=1; //Input data sampled at end of data output time 1
    
    //SPI Mode and clock
    SSP2CON1bits.SSPM=0b0010; //SPI Master Mode, clock = Fosc/64
    
    //SPI Enable
    SSP2CON1bits.SSPEN=1; //Enabled
    
    LoRaReset();
    __delay_ms(10);
    setLoRaMode();
    __delay_ms(10);
    LoRaOptimalLoad(syncWord);
    LoRaSetFrequency(freq); //Can only set in standby or sleep modes
}

uint8_t LoRaGetVersion(){
    uint8_t temp = SPI2ReadByte(VERSION_REG);
    return temp;
}

void LoRaReset(){
    //Perform reset
    TRISCbits.RC6=0; //Configure port as an output
    LATCbits.LATC6=0; //Set low
    __delay_ms(1);
    TRISCbits.RC6=1; //Configure port as input (goes high-Z)
    __delay_ms(5);
}

void setLoRaMode(){
    //Set Long Range Mode bit in OpMode register
    uint8_t regValue = readOpModeRegister();
    regValue = regValue | LORA_MODE; //Set bit 7 high and leave others as is
    writeOpModeRegister(regValue); //Write the value back
}

uint8_t readOpModeRegister(){
    return SPI2ReadByte(OP_MODE_REG);
}

void writeOpModeRegister(uint8_t regValue){
    SPI2WriteByte(OP_MODE_REG, regValue);
}



void LoRaMode_RXActive(){
    SPI2WriteByte(OP_MODE_REG, 0b1000101); //LoRa Mode with Receiver active all the time
}

/**
 * SPI2WriteByte
 * Writes an address byte, then writes a data byte
 * @param address
 * @param data
 */
void SPI2WriteByte(uint8_t address, uint8_t data){
    SSP2IF=0; //Clear interrupt flag
    LATDbits.LATD3=0; //Set SS low
    __delay_us(5);
    address = address|0x80; //bit 7 set to indicate a register write
    SSP2BUF=address; //Write address to SPI buffer 
    while(!SSP2IF){
        //Wait for transmission to complete
    }
    SSP2IF=0; //Clear interrupt flag
    __delay_us(5);
    SSP2BUF=data; 
    while(!SSP2IF){
        //Wait for transmission and reception to complete
    }
    __delay_us(5);
    LATDbits.LATD3=1; //Set SS high
    SSP2IF=0; //Clear interrupt flag
    uint8_t dataByte = SSP2BUF; //A byte has been received but this is not used.
}

/**
 * SPI2ReadByte
 * Writes an address byte then reads a byte back.  0 is sent as a dummy value
 * for the second transfer.
 * @param address
 * @return 
 */
uint8_t SPI2ReadByte(uint8_t address){
    SSP2IF=0; //Clear interrupt flag
    LATDbits.LATD3=0; //Set SS low
    SSP2BUF=address; //Write data to SPI buffer
    while(!SSP2IF){
        //Wait for transmission to complete
    }
    SSP2IF=0; //Clear interrupt flag
    SSP2BUF=0; //Data byte - for a read, set to 0
    while(!SSP2IF){
        //Wait for transmission and reception to complete
    }
    SSP2IF=0; //Clear interrupt flag
    //__delay_us(20);
    LATDbits.LATD3=1; //Set SS high
    uint8_t dataByte = SSP2BUF;
    return dataByte;
}

/* 
 * Transmits a data packet.
 */
void LoRaTXData(uint8_t* data, uint8_t dataLength){
    //Must be in standby mode for this to work
    LoRaStandbyMode();
    if(DEBUG){
        printf("Transmitting.... ");
    }
    SPI2WriteByte(FIFO_ADD_PTR_REG, 0);
    SPI2WriteByte(PAYLOAD_LENGTH_REG, 0);
    

    for(uint8_t i=0;i<dataLength;i++){
        SPI2WriteByte(FIFO_REG, data[i]);
    }
    SPI2WriteByte(PAYLOAD_LENGTH_REG, dataLength);
    LoRaTXMode(); //Set TX mode to send the message
    if(DEBUG){
        printf("Done.\r\n");
    }
    //Will return to standby mode automatically when finished.
    //You can check TxDone interrupt to see if it's finished.
}

/**
 * Sets the LoRa module into standby mode
 */
void LoRaStandbyMode(){
    uint8_t regValue = readOpModeRegister(); //Read whats in there already
    regValue = regValue & 0b11111000; //Blank out other modes
    regValue = regValue | STANDBY_MODE; //Set bit 0 high and leave others as is
    writeOpModeRegister(regValue); //Write the value back
}

void LoRaSleepMode(){
    uint8_t regValue = readOpModeRegister(); //Read whats in there already
    regValue = regValue & 0b11111000; //Blank out other modes
    regValue = regValue | SLEEP_MODE;
    writeOpModeRegister(regValue); //Write the value back
}

void LoRaFreqSynthRXMode(){
    uint8_t regValue = readOpModeRegister(); //Read whats in there already
    regValue = regValue & 0b11111000; //Blank out other modes
    regValue = regValue | FREQ_SYNTH_RX_MODE; //Set bit 0 high and leave others as is
    writeOpModeRegister(regValue); //Write the value back
}

void LoRaFreqSynthTXMode(){
    uint8_t regValue = readOpModeRegister(); //Read whats in there already
    regValue = regValue & 0b11111000; //Blank out other modes
    regValue = regValue | FREQ_SYNTH_TX_MODE; //Set bit 0 high and leave others as is
    writeOpModeRegister(regValue); //Write the value back
}

void LoRaTXMode(){
    if(DEBUG){
        printf("TX Mode\r\n");
    }
    uint8_t regValue = readOpModeRegister(); //Read whats in there already
    regValue = regValue & 0b11111000; //Blank out other modes
    regValue = regValue | TX_MODE; //Set bit 0 high and leave others as is
    writeOpModeRegister(regValue); //Write the value back
}

void LoRaRXContinuousMode(){
    uint8_t regValue = readOpModeRegister(); //Read whats in there already
    regValue = regValue & 0b11111000; //Blank out other modes
    regValue = regValue | RX_CONT_MODE; //Set bit 0 high and leave others as is
    writeOpModeRegister(regValue); //Write the value back02
}
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

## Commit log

2023-01-01 Add files via upload
    Project data upload
    [Electronics Box.stl, Electronics Cover.stl, Fan Holder.stl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]
2023-01-01 Add files via upload
    Uploaded sensor PCB and schematic images
2023-01-01 Add files via upload
    Add PCB and schematic images of the main sensor PCB.
